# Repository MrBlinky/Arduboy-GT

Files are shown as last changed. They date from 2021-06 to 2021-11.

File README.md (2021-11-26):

# Arduboy-GT

Homemade Arduboy using custom PCB, modules and all through hole parts and a 1.54" OLED display.

For more info check out the [Hackster.io Project](https://www.hackster.io/mrblinky/diy-arduboy-gt-2e4824)

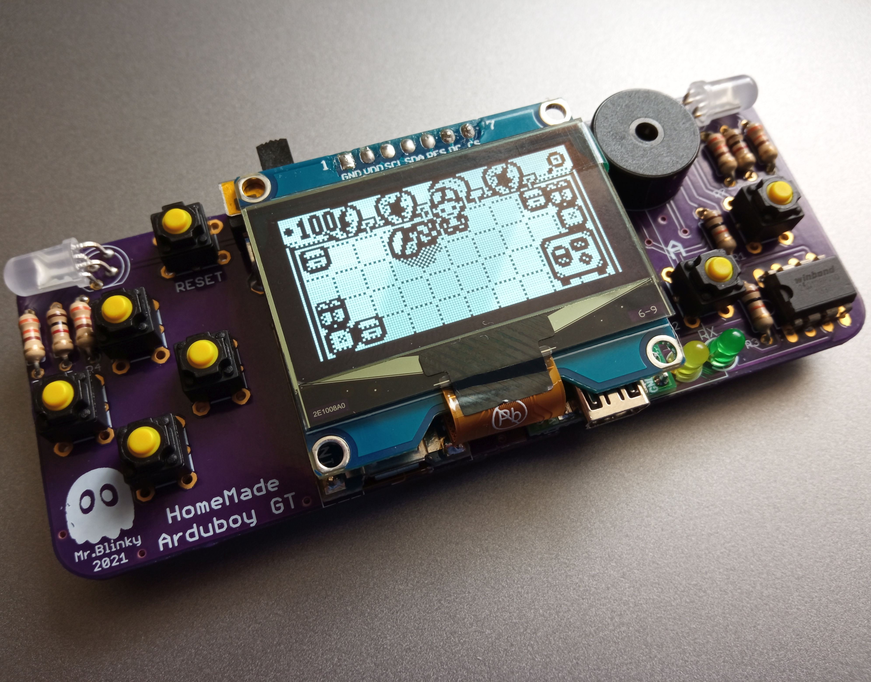
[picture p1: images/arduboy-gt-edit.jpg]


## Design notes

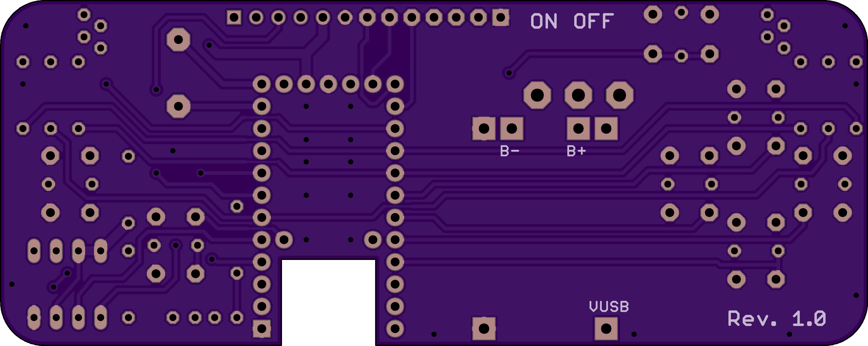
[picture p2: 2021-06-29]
eagle-cad/oshpark-pcb-bottom.png

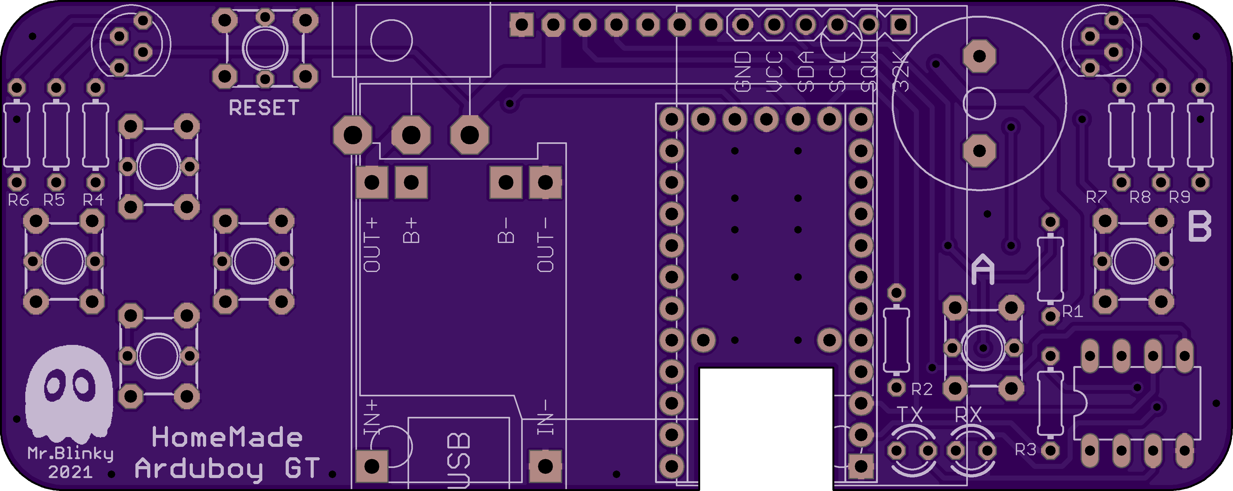
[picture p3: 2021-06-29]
eagle-cad/oshpark-pcb-top.png

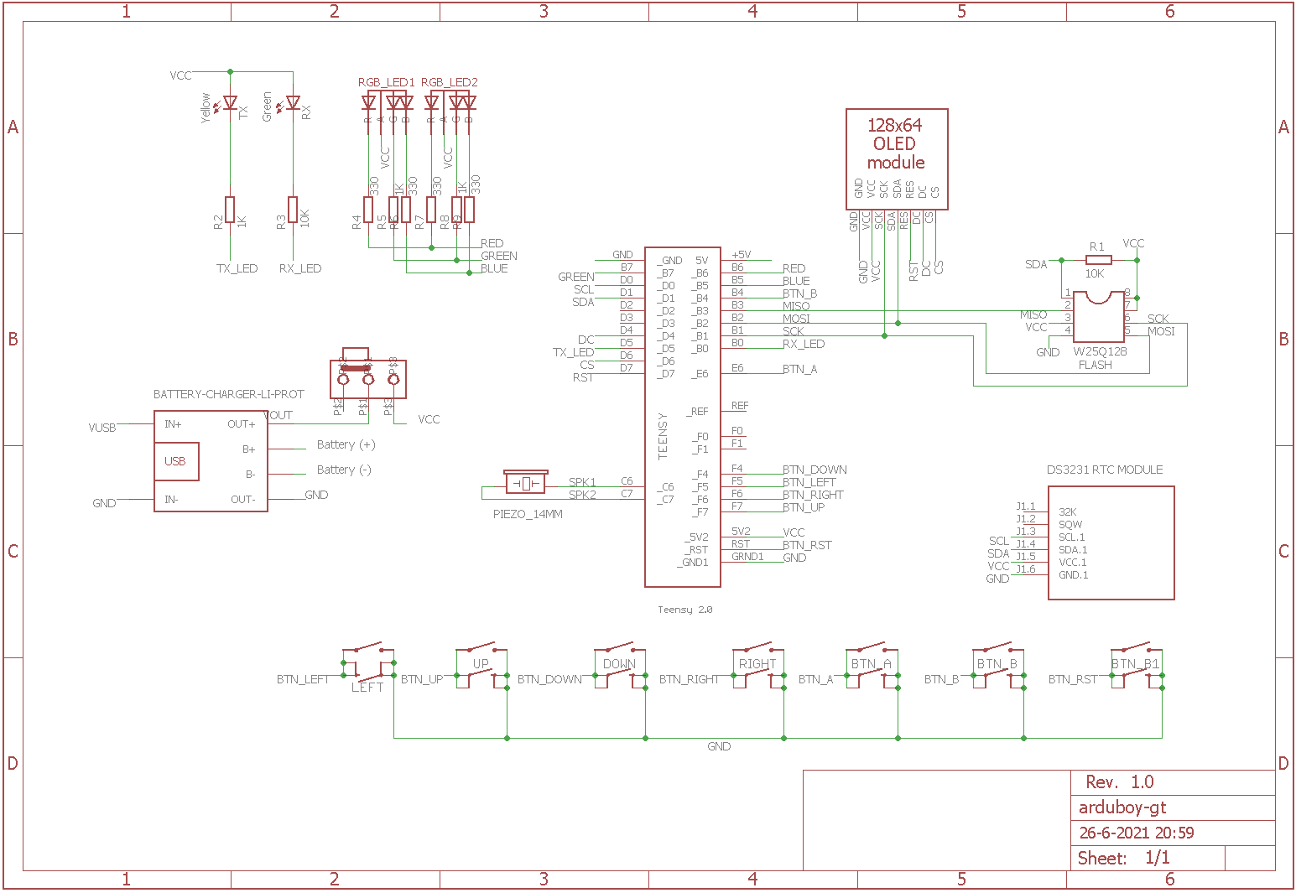
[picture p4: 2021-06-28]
eagle-cad/arduboy-gt.png

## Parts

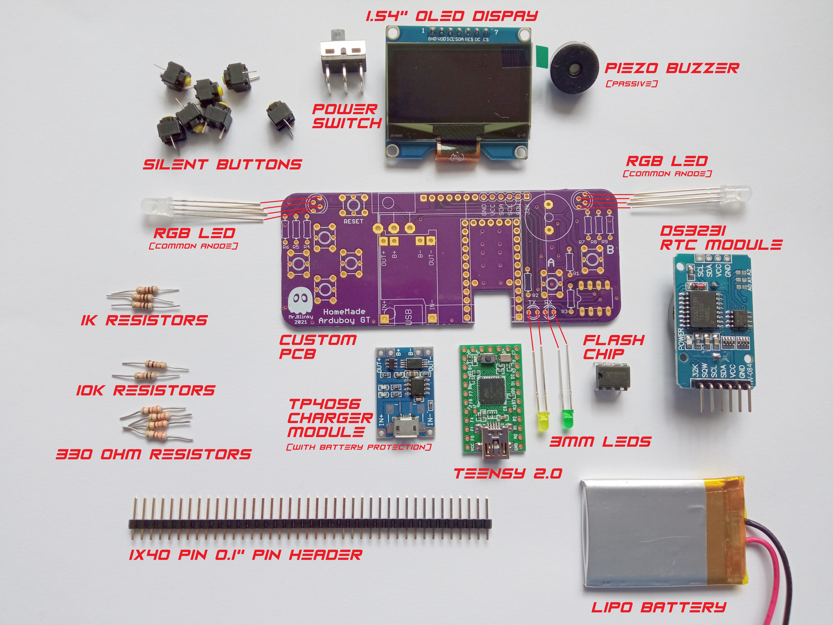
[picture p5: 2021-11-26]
images/parts-named.jpg

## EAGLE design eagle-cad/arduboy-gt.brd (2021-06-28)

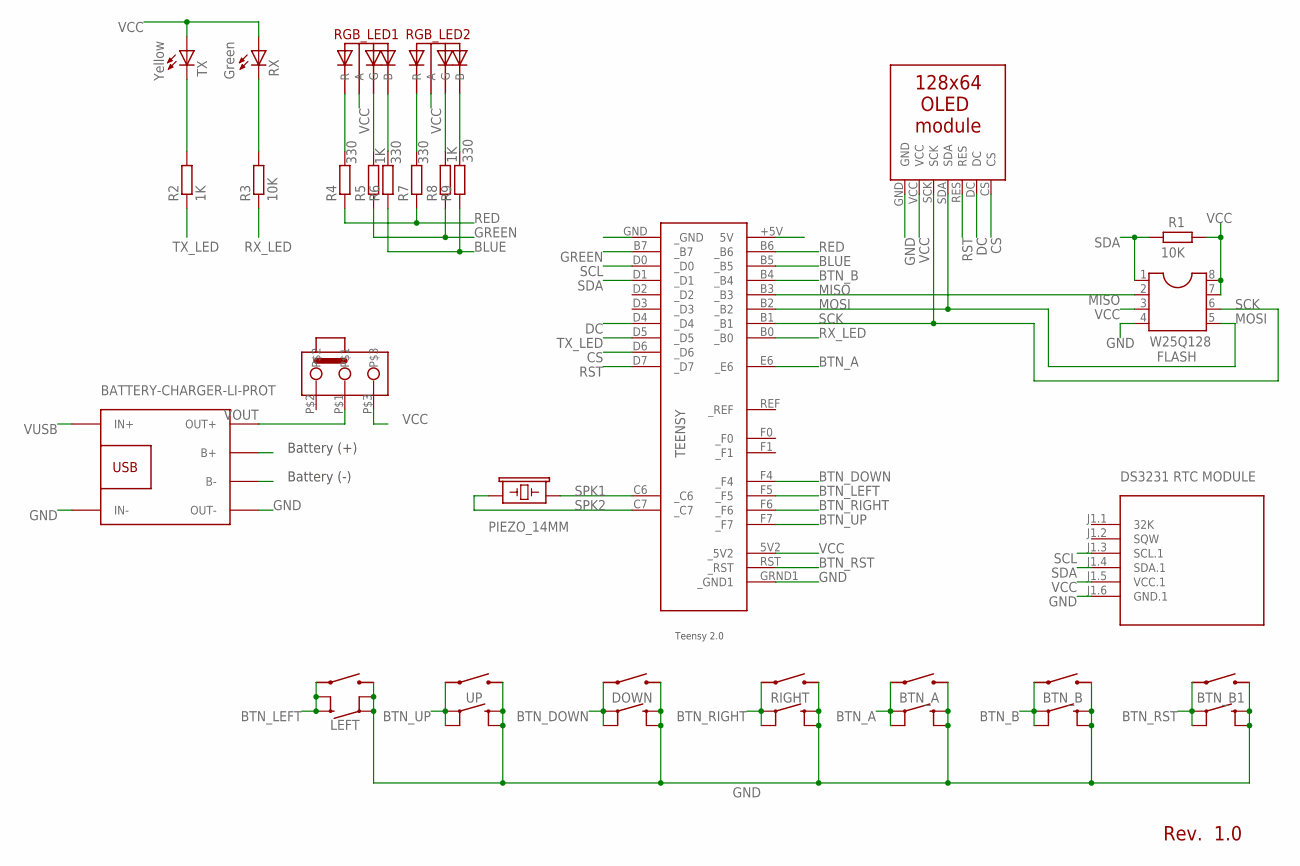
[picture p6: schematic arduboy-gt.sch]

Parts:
BTN_A: MOMENTARY-SWITCH-SPST-PTH-6.0MM; TACTILE_SWITCH_PTH_6.0MM
BTN_A_: KAIHLMICROSWITCH
BTN_B, BTN_B1: MOMENTARY-SWITCH-SPST-PTH-6.0MM; TACTILE_SWITCH_PTH_6.0MM
BTN_B_, BTN_B_1: KAIHLMICROSWITCH
DOWN: MOMENTARY-SWITCH-SPST-PTH-6.0MM; TACTILE_SWITCH_PTH_6.0MM
DOWN_: KAIHLMICROSWITCH
FLASH: W25Q128; DIL08
LEFT: MOMENTARY-SWITCH-SPST-PTH-6.0MM; TACTILE_SWITCH_PTH_6.0MM
LEFT_: KAIHLMICROSWITCH
R1, R3: 10K; 0204/7
R2, R5, R8: 1K; 0204/7
R4, R6, R7, R9: 330; 0204/7
RGB_LED1, RGB_LED2: 5MMRGBLED-CA; LED5MMRGB
RIGHT: MOMENTARY-SWITCH-SPST-PTH-6.0MM; TACTILE_SWITCH_PTH_6.0MM
RIGHT_: KAIHLMICROSWITCH
RX: TLLG4400; LED3MM
SG1: PIEZO_14MM
TX: TLLY4400; LED3MM
U$1: OLED
U$2: SWITCH
U$3: BATTERY-CHARGER-LI-PROT
U$6: DS3231 RTC MODULE; RTC-DS3231-AT24C32
UP: MOMENTARY-SWITCH-SPST-PTH-6.0MM; TACTILE_SWITCH_PTH_6.0MM
UP_: KAIHLMICROSWITCH
_1: TEENSY

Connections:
BLUE: R6.1, R9.1, _1.B5 (_B5)
BTN_A: BTN_A.1, BTN_A.2, BTN_A_.P$1, _1.E6 (_E6)
BTN_B: BTN_B.1, BTN_B.2, BTN_B_.P$1, _1.B4 (_B4)
BTN_DOWN: DOWN.1, DOWN.2, DOWN_.P$1, _1.F4 (_F4)
BTN_LEFT: LEFT.3, LEFT.4, LEFT_.P$1, _1.F5 (_F5)
BTN_RIGHT: RIGHT.1, RIGHT.2, RIGHT_.P$1, _1.F6 (_F6)
BTN_RST: BTN_B1.1, BTN_B1.2, BTN_B_1.P$1, _1.RST (_RST)
BTN_UP: UP.1, UP.2, UP_.P$1, _1.F7 (_F7)
CS: U$1.CS, _1.D6 (_D6)
DC: U$1.DC, _1.D4 (_D4)
GND: BTN_A.3, BTN_A.4, BTN_A_.P$2, BTN_B.3, BTN_B.4, BTN_B1.3, BTN_B1.4, BTN_B_.P$2, BTN_B_1.P$2, DOWN.3, DOWN.4, DOWN_.P$2, FLASH.4, LEFT.1, LEFT.2, LEFT_.P$2, RIGHT.3, RIGHT.4, RIGHT_.P$2, U$1.GND, U$3.IN-, U$3.OUT-, U$6.J1.6 (GND.1), UP.3, UP.4, UP_.P$2, _1.GND (_GND), _1.GRND1 (_GND1)
GREEN: R5.1, R8.1, _1.B7 (_B7)
MISO: FLASH.2, _1.B3 (_B3)
MOSI: FLASH.5, U$1.SDA, _1.B2 (_B2)
unnamed: R7.2, RGB_LED2.R$1 (R)
unnamed: R8.2, RGB_LED2.G$1 (G)
unnamed: R9.2, RGB_LED2.B$1 (B)
unnamed: R6.2, RGB_LED1.B$1 (B)
unnamed: R5.2, RGB_LED1.G$1 (G)
unnamed: R4.2, RGB_LED1.R$1 (R)
RED: R4.1, R7.1, _1.B6 (_B6)
RST: U$1.RES, _1.D7 (_D7)
RX_LED: R3.1, _1.B0 (_B0)
RX_LED_R: R3.2, RX.K (C)
SCK: FLASH.6, U$1.SCK, _1.B1 (_B1)
SCL: U$6.J1.3 (SCL.1), _1.D0 (_D0)
SDA: FLASH.1, R1.2, U$6.J1.4 (SDA.1), _1.D1 (_D1)
SPK1: SG1.P$2, _1.C6 (_C6)
SPK2: SG1.P$1, _1.C7 (_C7)
TX_LED: R2.1, _1.D5 (_D5)
TX_LED_R: R2.2, TX.K (C)
VCC: FLASH.3, FLASH.7, FLASH.8, R1.1, RGB_LED1.C$1 (A), RGB_LED2.C$1 (A), RX.A, TX.A, U$1.VCC, U$2.P$3, U$6.J1.5 (VCC.1), _1.5V2 (_5V2), _1.+5V (5V)
VOUT: U$2.P$1, U$3.OUT+
VUSB: U$3.IN+

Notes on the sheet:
Battery (-)
Battery (+)
Green
Yellow
Rev. 1.0

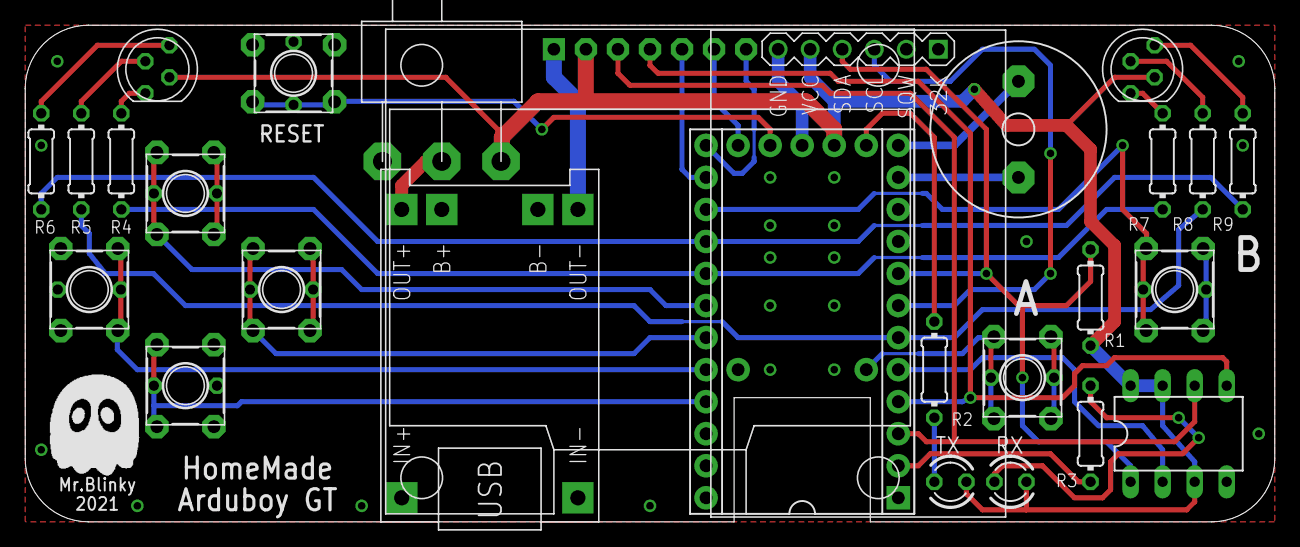
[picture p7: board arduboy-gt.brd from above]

Board: 2 copper layers, 99.1 x 39.4 mm, 34 parts (0 on the bottom side), 33 nets.

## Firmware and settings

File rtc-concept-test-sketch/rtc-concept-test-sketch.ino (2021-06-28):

// read DS3231 and FX data proof of concept test June 2021 by Mr. Blinky

// (Build with Arduboy Homemade package installed)

#include <Arduboy2.h> // include Arduboy2 library
#include <ArduboyFX.h>
#include <Sprites.h>
#include "ds3231.h"
#include "i2c.h"
#include "gfx/largeDigits.h"
#include "gfx/smallDigits.h"
#include "gfx/timeSeperator.h"
#include "gfx/dateSeperator.h"

Arduboy2 arduboy;
DS3231_time ds3231;

//assign values;
void setup() {
  arduboy.begin(); //initialisation with startup logo
  FX::disableOLED();
  FX::begin();

#if 0 //set date and time hack
  i2c_enable();
  i2c_start(SLAVE_ADDRESS_WRITE(DS3231_slaveAddress));
  i2c_write(DS3221_time_seconds);
  i2c_write(0x00);
  i2c_write(0x02);
  i2c_write(0x17);
  i2c_write(0x01);
  i2c_write(0x27);
  i2c_write(0x06);
  i2c_write(0x21);
  i2c_stop();
  i2c_disable();
 #endif
 
#if 0 //enable RTC hack
  i2c_enable();
  i2c_start(SLAVE_ADDRESS_WRITE(DS3231_slaveAddress));
  i2c_write(DS3221_control);
  i2c_write(0x04);
  i2c_stop();
  i2c_disable();
#endif
}

void loop() {
  if (!arduboy.nextFrame()) return; // Do nothing until it's time for the next frame

  //load FX loader screen graphic to display buffer
  FX::seekCommand(SFC_READ, (uint24_t)0x000100); //Flash address of Loader menu graphics
  SPDR = 0;
  FX::readBytesEnd(arduboy.sBuffer, WIDTH * HEIGHT / 8);

  //read DS3231 time
  i2c_enable();
  i2c_start(SLAVE_ADDRESS_WRITE(DS3231_slaveAddress));
  i2c_write(DS3221_time_seconds);
  i2c_stop();
  i2c_start(SLAVE_ADDRESS_READ(DS3231_slaveAddress ));
  //read directly into time structure
  uint8_t*p = (uint8_t*)&ds3231;
  for(uint8_t i = 0; i < (sizeof(ds3231) - 1); ++i) *p++ = i2c_readAck();
  *p = i2c_readNack(); // read last byte
  i2c_stop();
  i2c_disable();

  
  //display time
  Sprites::drawSelfMasked(119,24,smallDigits,ds3231.seconds >> 4);
  Sprites::drawSelfMasked(124,24,smallDigits,ds3231.seconds & 0x0F);
  Sprites::drawSelfMasked(102,16,timeSeperator,0);
  Sprites::drawSelfMasked(105,16,largeDigits,ds3231.minutes >> 4);
  Sprites::drawSelfMasked(112,16,largeDigits,ds3231.minutes & 0x0F);
  Sprites::drawSelfMasked(88,16,largeDigits,ds3231.hours >> 4);
  Sprites::drawSelfMasked(95,16,largeDigits,ds3231.hours & 0x0F);
  //display date
  Sprites::drawSelfMasked(26,16,largeDigits,ds3231.date >> 4);
  Sprites::drawSelfMasked(33,16,largeDigits,ds3231.date & 0x0F);
  Sprites::drawSelfMasked(21,16,dateSeperator,0);
  Sprites::drawSelfMasked( 7,16,largeDigits,ds3231.month >> 4);
  Sprites::drawSelfMasked(14,16,largeDigits,ds3231.month & 0x0F);
  
  FX::enableOLED();
  arduboy.display(CLEAR_BUFFER); //clears display after displaying display buffer
  FX::disableOLED();
}

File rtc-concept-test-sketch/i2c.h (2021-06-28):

#pragma once

//I2C lite library for Arduboy

//Macros
#define SLAVE_ADDRESS_WRITE(a) ((a << 1) | 0)
#define SLAVE_ADDRESS_READ(a)  ((a << 1) | 1)

#define I2C_SPEED 400000L // 400Kbps bitrate

//I2C pins
#define I2C_PORT  PORTD
#define I2C_DDR   DDRD
#define I2C_PIN   PIND
#define I2C_SCL   PORTD0
#define I2C_SDA   PORTD1

void i2c_wait()
{
  while (!(TWCR & _BV(TWINT)));  
}

void i2c_enable()
{
  PRR0 &= ~_BV(PRTWI);                   // disable TWI power reduction (enabled by Arduboy2 library)
  PORTD |= _BV(I2C_SDA);                 // pullups / inactive SDA flashchipselect
  PORTD |= _BV(I2C_SCL);
  DDRD  |= _BV(I2C_SDA);                 // outputs (irrellevant until TWI enabled)
  DDRD  |= _BV(I2C_SCL);
  TWSR  &= ~(_BV(TWPS1) | _BV(TWPS0));   // set I2C prescaler
  TWBR = ((F_CPU / I2C_SPEED) - 16) / 2; // configure bitrate
  //TWCR = _BV(TWEN) | _BV(TWEA);          // enable TWI and change pin function, enable ACKs
}

void i2c_disable()
{
  TWCR = 0;           // disable TWI and restore normal pin function (SDA and SCL become active high outputs)
  PRR0 |= _BV(PRTWI); // enable TWI power reduction
}

void i2c_write(uint8_t data)
{
  TWDR = data;
  TWCR = _BV(TWINT) | _BV(TWEN);              // start transmission of data
  i2c_wait();                                 // wait for data to be transmitted  
}

void i2c_start(uint8_t slaveAddrReadWrite)
{
  TWCR = _BV(TWINT) | _BV(TWSTA) | _BV(TWEN); // send start condition
  i2c_wait();                                 // wait for start condition to be transmitted  
  i2c_write(slaveAddrReadWrite);
}

void i2c_stop()
{
  TWCR = _BV(TWINT) | _BV(TWSTO) | _BV(TWEN); // send stop condition
}

uint8_t i2c_readAck(void)
{
  TWCR = _BV(TWINT)|_BV(TWEN)|_BV(TWEA); 
  i2c_wait();
  return TWDR;
}

uint8_t i2c_readNack(void)  // used for reading last byte
{
  TWCR = _BV(TWINT)|_BV(TWEN);
  i2c_wait();
  return TWDR;
}

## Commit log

2021-06-28 Add Eagle files and test sketch
    [arduboy-gt.brd, arduboy-gt.sch]
2021-06-29 add oshpark pcb images

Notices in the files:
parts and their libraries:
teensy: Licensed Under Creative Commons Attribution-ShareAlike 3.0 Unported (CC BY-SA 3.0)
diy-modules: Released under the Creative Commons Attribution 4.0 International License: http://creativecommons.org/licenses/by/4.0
